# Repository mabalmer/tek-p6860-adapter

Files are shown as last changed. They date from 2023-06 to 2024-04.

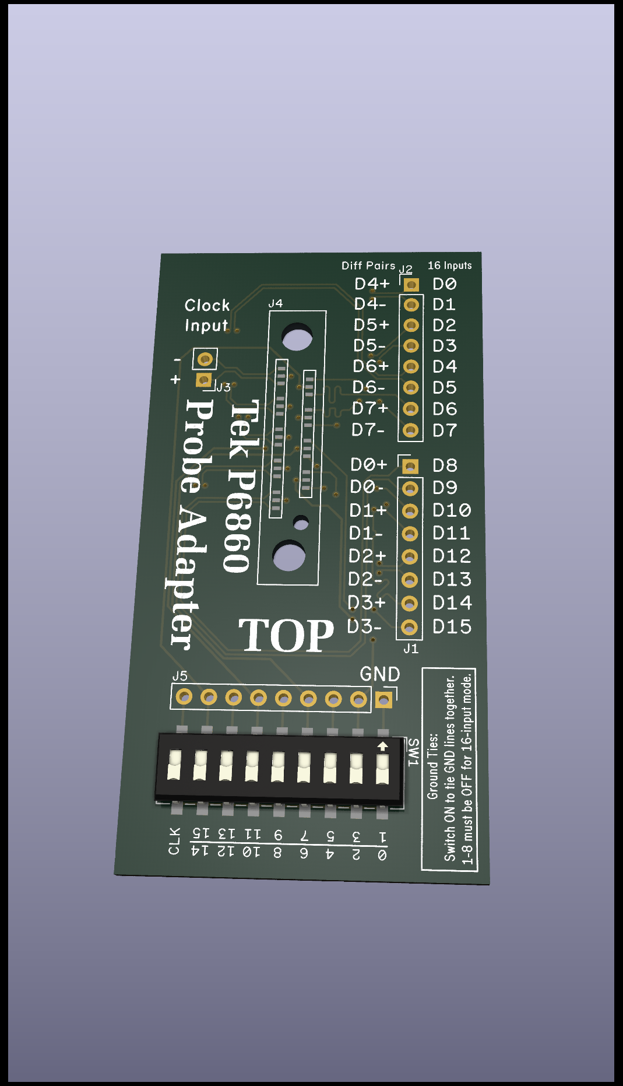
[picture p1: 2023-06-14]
Tek P6860 Adapter v.2-TOP.png

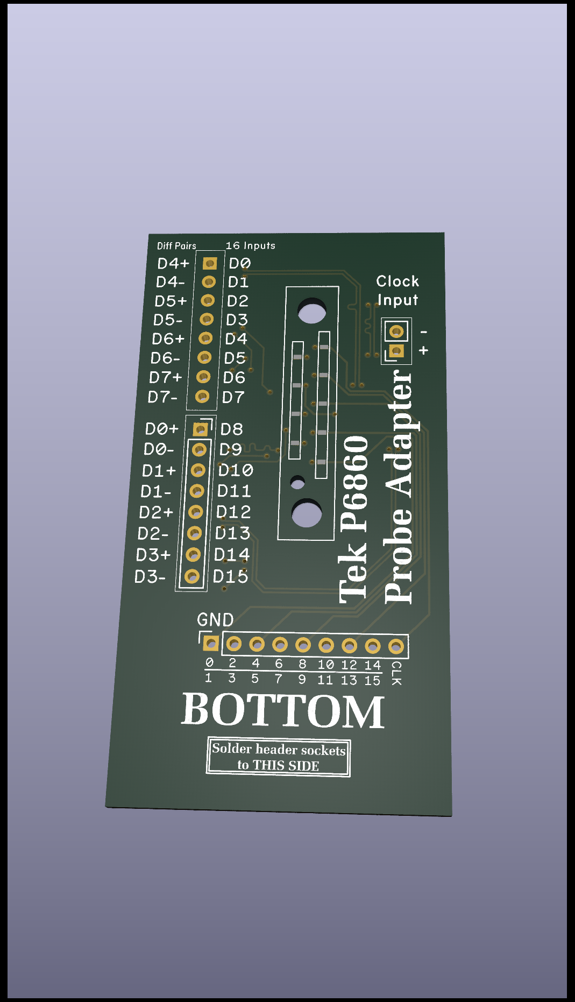
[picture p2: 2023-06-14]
Tek P6860 Adapter v.2/Tek P6860 Adapter v.2-BOT.png

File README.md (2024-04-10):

# tek-p6860-adapter

This board is designed to take the Tektronix P6860 compression probe found on many Tektronix logic analyzers and break them out into 0.1" header. It includes a single 9-position SMD DIP switch so that you can individually choose to tie the grounds together to allow single-ended mode usage for the individual inputs. 

The Library folder contains a KiCad symbol and footprint for the probe pad layout.

The base schematic uses J-lead SMD DIP switches to save space, but there is an alternate set of gerber files for gull-wing lead DIP switches in the main directory. 

I've selected a set of wire-wrap style 0.1" header strips that go through the board, allowing you to use headers that have sockets as well as pins on the ones I've built myself. The Digi-Key part number for this is SAM1125-32-ND.

The matching gull-wing DIP switch part number is CT2199LPST-ND.

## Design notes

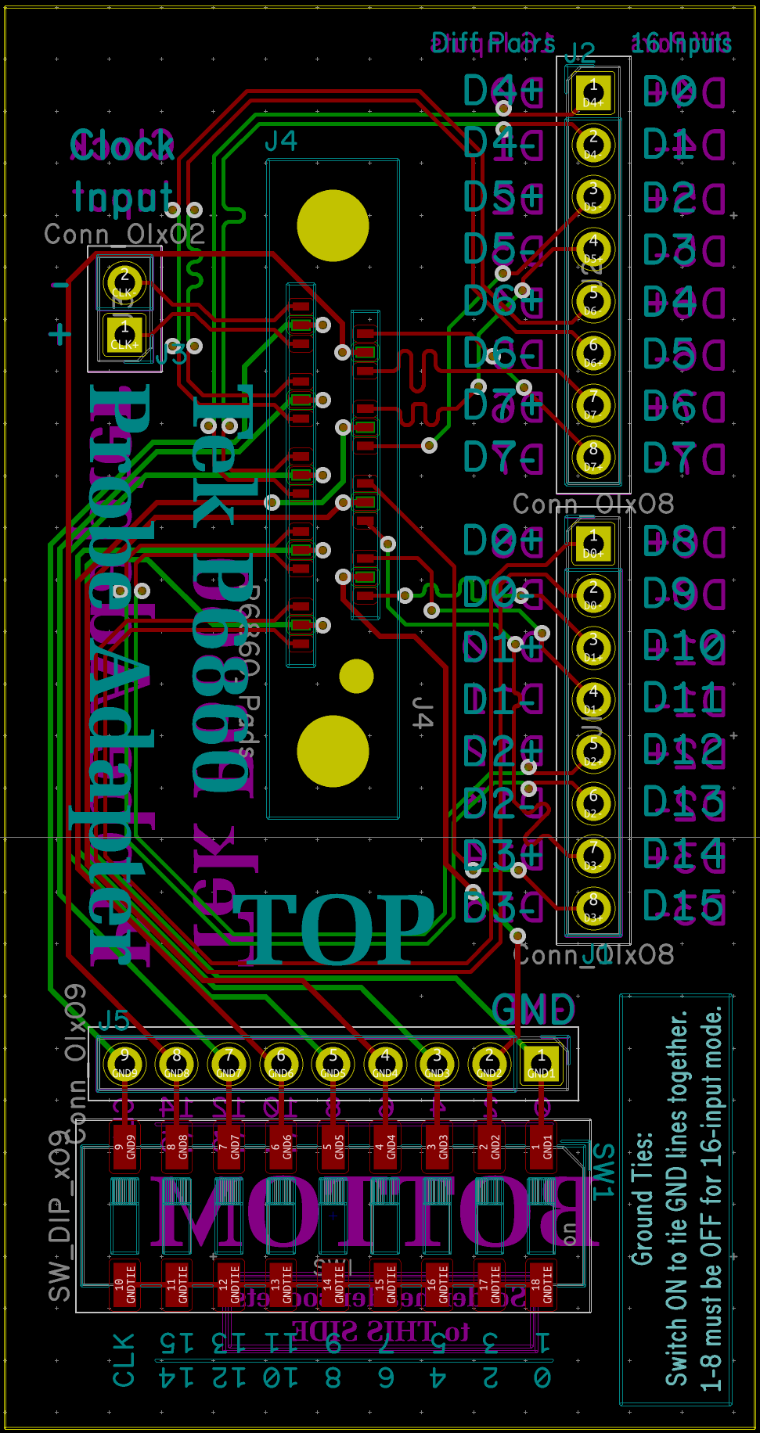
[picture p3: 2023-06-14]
Tek P6860 Adapter v.2/layout.png

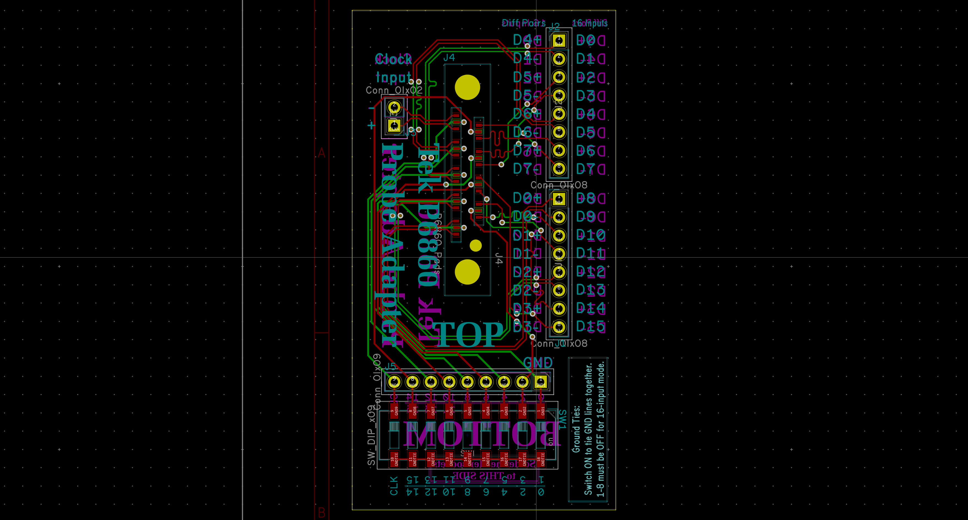
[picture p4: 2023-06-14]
Tek P6860 Adapter v.2/Tek P6860 Adapter v.2-TOP.png

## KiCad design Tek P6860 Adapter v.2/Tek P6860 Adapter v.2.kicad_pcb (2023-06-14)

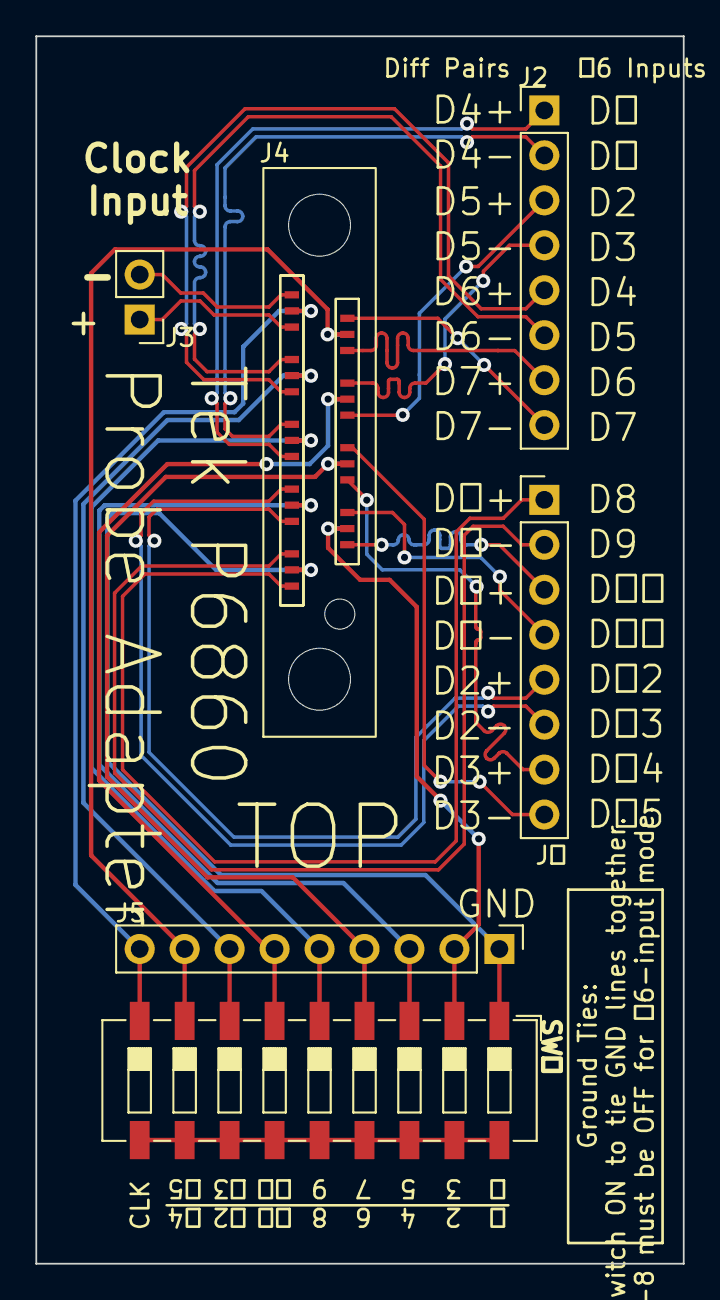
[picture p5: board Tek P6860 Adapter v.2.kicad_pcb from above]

Board: 2 copper layers, 36.6 x 69.3 mm, 6 parts (0 on the bottom side), 28 nets.

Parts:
J1, J2: Conn_01x08; PinHeader_1x08_P2.54mm_Vertical
J3: Conn_01x02; PinHeader_1x02_P2.54mm_Vertical
J4: P6860_Pads; Tek_6860_Footprint
J5: Conn_01x09; PinHeader_1x09_P2.54mm_Vertical
SW1: SW_DIP_x09; SW_DIP_SPSTx09_Slide_6.7x24.42mm_W6.73mm_P2.54mm_LowProfile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

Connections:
/CLK+: J3.1, J4.A13 (CLK+)
/CLK-: J3.2, J4.A15 (CLK-)
/D0+: J1.1, J4.A1 (D0)
/D0-: J1.2, J4.A3 (D1)
/D1+: J1.3, J4.B1 (D2)
/D1-: J1.4, J4.B3 (D3)
/D2+: J1.5, J4.A4 (D4)
/D2-: J1.6, J4.A6 (D5)
/D3+: J1.8, J4.B6 (D7)
/D3-: J1.7, J4.B4 (D6)
/D4+: J2.1, J4.A7 (D8)
/D4-: J2.2, J4.A9 (D9)
/D5+: J2.4, J4.B9 (D11)
/D5-: J2.3, J4.B7 (D10)
/D6+: J2.6, J4.A12 (D13)
/D6-: J2.5, J4.A10 (D12)
/D7+: J2.8, J4.B12 (D15)
/D7-: J2.7, J4.B10 (D14)
/GND1: J4.A2 (GND), J5.1, SW1.1
/GND2: J4.B2 (GND), J5.2, SW1.2
/GND3: J4.A5 (GND), J5.3, SW1.3
/GND4: J4.B5 (GND), J5.4, SW1.4
/GND5: J4.A8 (GND), J5.5, SW1.5
/GND6: J4.B8 (GND), J5.6, SW1.6
/GND7: J4.A11 (GND), J5.7, SW1.7
/GND8: J4.B11 (GND), J5.8, SW1.8
/GND9: J4.A14 (GND), J5.9, SW1.9
/GNDTIE: SW1.10, SW1.11, SW1.12, SW1.13, SW1.14, SW1.15, SW1.16, SW1.17, SW1.18

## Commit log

2023-06-14 Add files via upload
    initial commit
    [Tek P6860 Adapter v.2-B_Cu.gbl, Tek P6860 Adapter v.2-B_Mask.gbs, Tek P6860 Adapter v.2-B_Paste.gbp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]
2023-06-14 Add files via upload
    silkscreen fix
    [Tek P6860 Adapter v.2-B_Cu.gbl, Tek P6860 Adapter v.2-B_Mask.gbs, Tek P6860 Adapter v.2-B_Paste.gbp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]
2023-06-28 Add gerbers for gull-wing lead DIP switches
    [Tek P6860 Adapter v.2-B_Cu.gbl, Tek P6860 Adapter v.2-B_Mask.gbs, Tek P6860 Adapter v.2-B_Paste.gbp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]
2024-04-10 Add header/switch part numbers
